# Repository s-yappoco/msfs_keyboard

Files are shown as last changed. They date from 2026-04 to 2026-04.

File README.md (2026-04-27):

# MSFS Macro Keyboard for PS5

PS5版 Microsoft Flight Simulator 2024 (MSFS2024) に最適化した、27キー、7ロータリーエンコーダー搭載の自作マクロキーボードです。

## 特徴
* **PS5完全対応**: PS5版 MSFS2024 での動作を確認済み。
* **Vial対応**: 専用ソフトのインストール不要。ブラウザ上で簡単にキーアサインを変更できます。
* **膨大なレイヤー数**: 最大16レイヤーに対応し、機体ごとの複雑な操作も割り当て可能。
* **高度なマクロ**: 複雑なキーシーケンスをワンタップで実行。
* **LEDインジケーター**:
    * **SIM Rate確認**: 4番目のLEDの色で、現在のSIM Rateを視覚的に判別可能（ユーザーキーコード制御）。
    * **レイヤー確認**: 5番目のLEDの色で、現在選択中のレイヤーを一目で把握。

## 外観
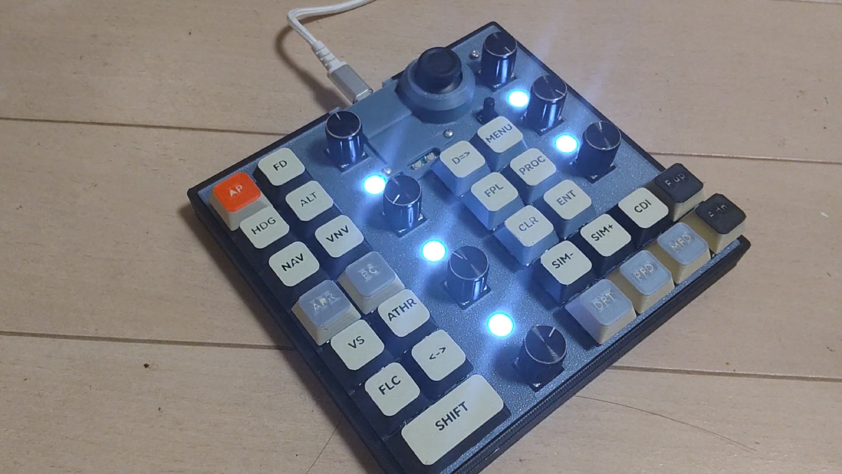
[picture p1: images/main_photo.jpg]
マクロキーボードの写真


## 基板の入手方法
本プロジェクトの専用プリント基板（PCB）は、メルカリにて頒布しています。
「**#MSFS2024自作キーボード**」で検索してください。
[メルカリで探す](https://jp.mercari.com/search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)

※基板とケースがセットになったものも、メルカリにて頒布を予定しています。

## 本キーボードの紹介 youtube
組み立ての様子、ファームウェアの書き込み、動作確認、MSFS2024 PS5版でのデモンストレーションをYouTubeで公開しています。
[youtubeで開く](https://youtu.be/_a79jdPi4Ig)

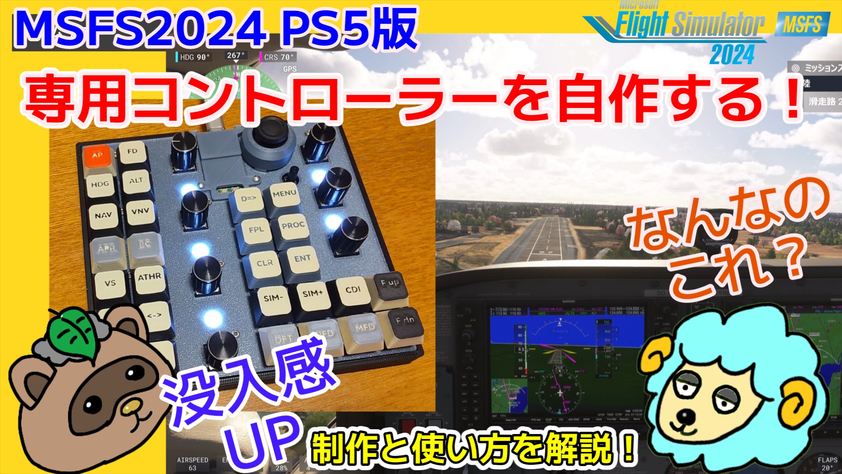
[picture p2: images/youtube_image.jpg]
youtube


## 回路図
[回路図(PDF)](msfs_keyboard_schematic.pdf)

## 必要部材 (BOM)

| リファレンス名 | 部品 | 数量 | 型式など | 主な入手先 |
| :--- | :--- | :---: | :--- | :--- |
| U1 | CPU基板 | 1 | RP2040マイコンボードキット | [秋月電子通商](https://akizukidenshi.com/catalog/g/g117542/) |
|　( SW1-19, SW21-28) | キースイッチ | 27 | cherry MX互換スイッチ | [遊舎工房でさがす](https://shop.yushakobo.jp/collections/cherry-mx-clone) |
| SW1-19, SW21-28 | キースイッチソケット | 27 | Kailh Switch Socket(MX用) | [遊舎工房](https://shop.yushakobo.jp/products/a01ps?variant=37665172521121) |
| RSW1-RSW7 | ロータリーエンコーダ | 7 | EC11 互換品 | [Amazon](https://www.amazon.co.jp/dp/B0C9QH83N6?ref=ppx_yo2ov_dt_b_fed_asin_title&th=1) |
| JSTICK1 | ジョイスティック | 1 | RKJXV122400R(アルプスアルパイン) | [秋月電子通商](https://akizukidenshi.com/catalog/g/g115951/) |
| SW20 | リセットスイッチ | 1 | TVD01-G73BB | [秋月電子通商](https://akizukidenshi.com/catalog/g/g109824/) |
| D1-D36 | ダイオード(SMD) | 36 | 1N4148W 互換 | [遊舎工房](https://shop.yushakobo.jp/products/a0800di-02-100) |
| LED1-LED5 | フルカラーLED | 5 | WS2812B 互換 | [遊舎工房](https://shop.yushakobo.jp/products/a0800ws-01-10) |
| C1-C5 | セラミックコンデンサ 0.1uF | 5 | 1608サイズ (省略可) | [秋月電子通商](https://akizukidenshi.com/catalog/g/g113374/) |
| - | インサートナット | 15 | M2 雌ねじ用(直径3mm×高さ3mm) | [Amazon](https://www.amazon.co.jp/dp/B0CTTLJL6S?ref=ppx_pop_dt_b_product_details&th=1) |
| - | パネル固定ねじ | 13 | M2ねじ 10mm | ホームセンター等 |
| - | CPUカバー取り付けねじ | 2 | M2ねじ 5mm | ホームセンター等 |
| - | アナログスティック交換用 | 1 | PS4コントローラ用 等 | [Amazon](https://www.amazon.co.jp/dp/B0C7C78LKB?ref=ppx_yo2ov_dt_b_fed_asin_title) |

## 筐体の入手方法
`3Dmodel_STL` フォルダにケース本体、トップパネル、ジョイスティックカバー、CPUカバーのSTLファイルを格納しています。<br>
3Dプリンターを用い、一般的なPLA素材での印刷が可能です。<br>
※基板とケースがセットになったものも、メルカリにて頒布を予定しています。
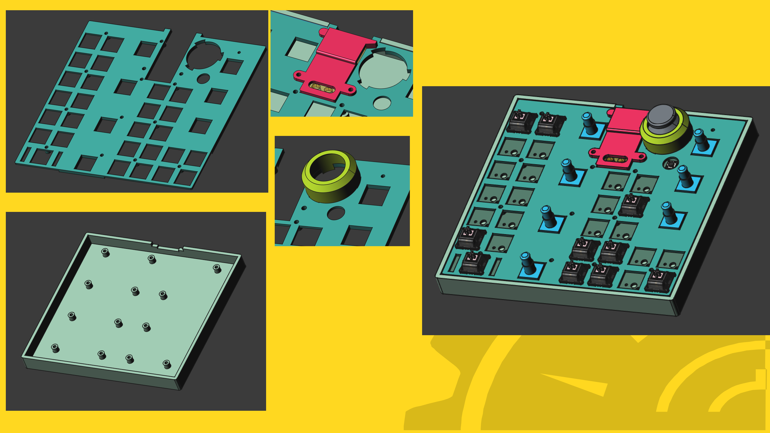
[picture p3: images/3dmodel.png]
3D model


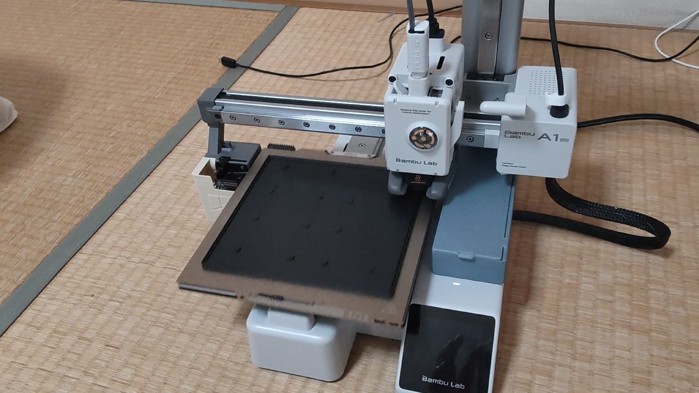
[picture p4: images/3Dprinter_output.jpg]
3Dプリンターでの印刷


## 組み立てに必要な道具
* **工具**: はんだごて、はんだ、ピンセット、ドライバー
* **あると便利なもの**: 虫めがね、テスター（導通確認用）
* **設定用**: PC、USBケーブル（ファームウェア書き込み・キーアサイン変更用）

## キーキャップの入手方法
市販のキーキャップのほか、3Dプリンターでの制作も可能です。

* **Keycap Generator**: [makerworldで開く](https://makerworld.com/en/models/1378891-keycap_generator#profileId-1426845)
  * このツールを利用して印刷したキーキャップのデータも `3Dmodel_STL` フォルダに同梱しています。(keycap_bambu.3mf)

## 設定方法
1. [Vial Web](https://get.vial.today/) にアクセスします。
2. キーボードを接続し、ブラウザ上でキーアサインやマクロを自由に編集してください。

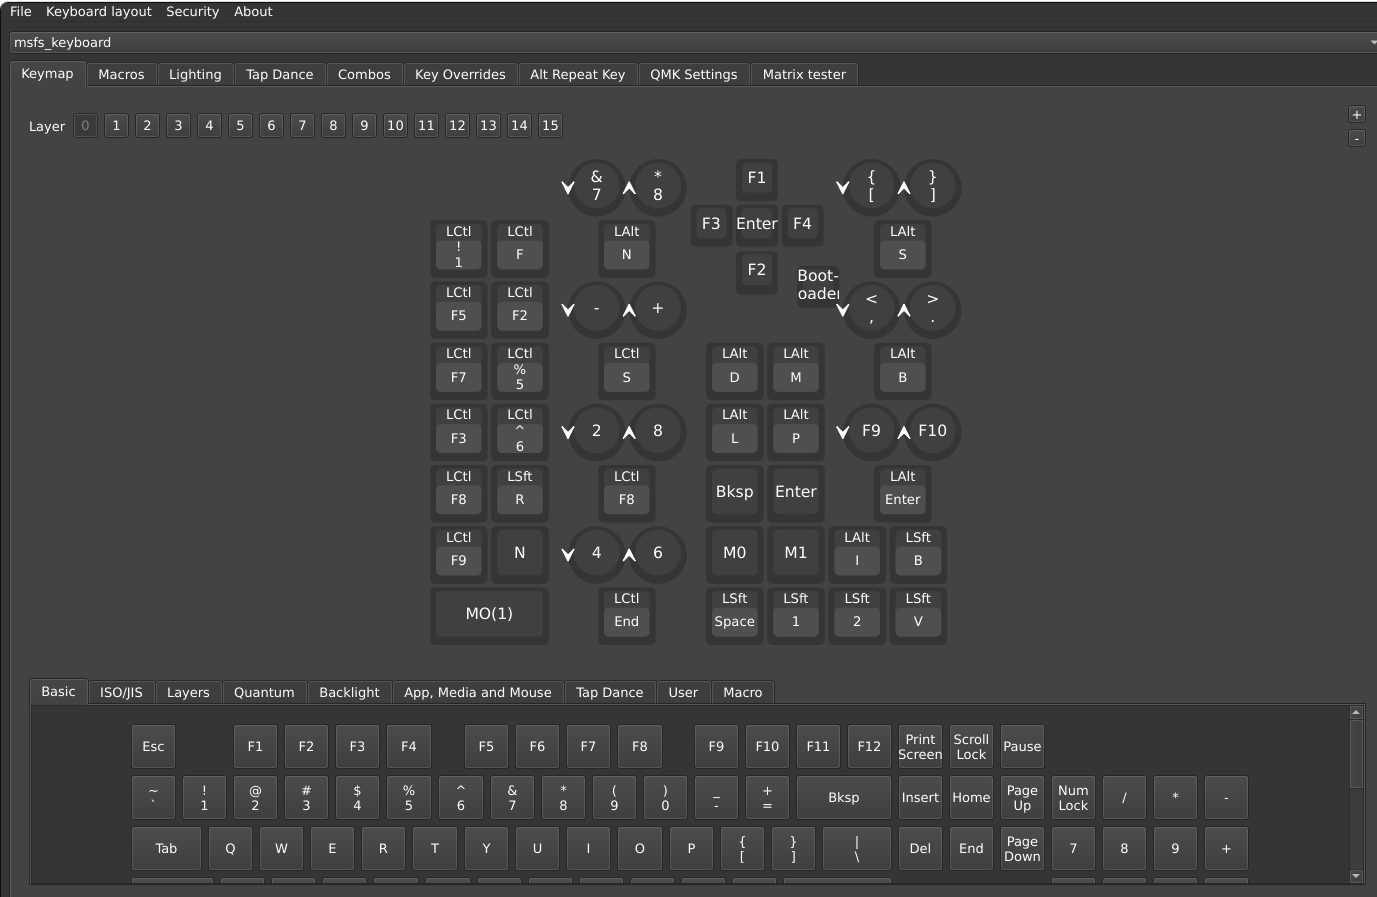
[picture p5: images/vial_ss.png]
Vial設定画面


## 開発環境
* Firmware: QMK / Vial
* MCU: RP2040

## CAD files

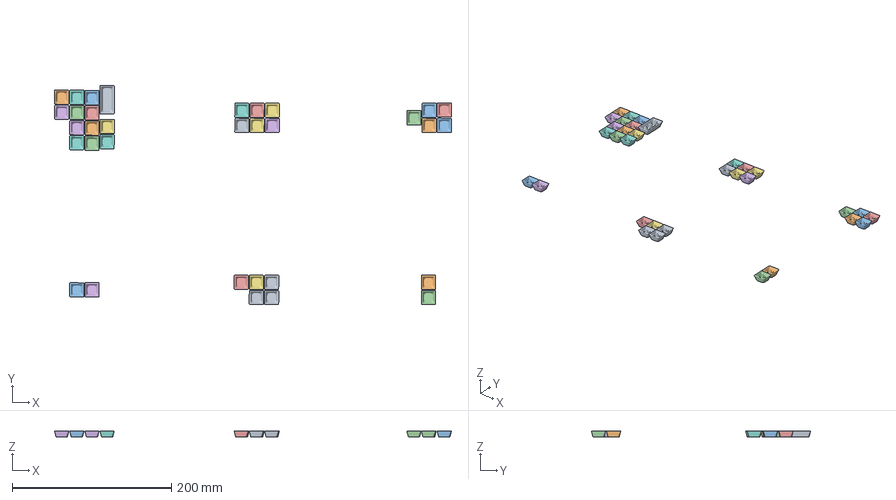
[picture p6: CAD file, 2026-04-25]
3Dmodel_STL/keycap_bambu.3mf
498.4 x 275.4 x 8.01 mm
shift_key.stl
Fup.stl
SIM_M.stl
Fdn.stl
SIM_P.stl
DISC.stl x 2
ATHR.stl
FLC.stl
Parametric_Model_Maker_1_3
Parametric_Model_Maker_1_2
Parametric_Model_Maker_1_17
Parametric_Model_Maker_1_22
Parametric_Model_Maker_1_6
Parametric_Model_Maker_1_4
Parametric_Model_Maker_1_24
Parametric_Model_Maker_1_15
Parametric_Model_Maker_1_23
Parametric_Model_Maker_1_1
Parametric_Model_Maker_1_18
Parametric_Model_Maker_1_21
Parametric_Model_Maker_1_16
Parametric_Model_Maker_1_10
Parametric_Model_Maker_1_14
Parametric_Model_Maker_1_5
Parametric_Model_Maker_1_19
Parametric_Model_Maker_1_20
Parametric_Model_Maker_1_13
Parametric_Model_Maker_1_9
Parametric_Model_Maker_1_7
Parametric_Model_Maker_1_8
Parametric_Model_Maker_1_11
Parametric_Model_Maker_1_12

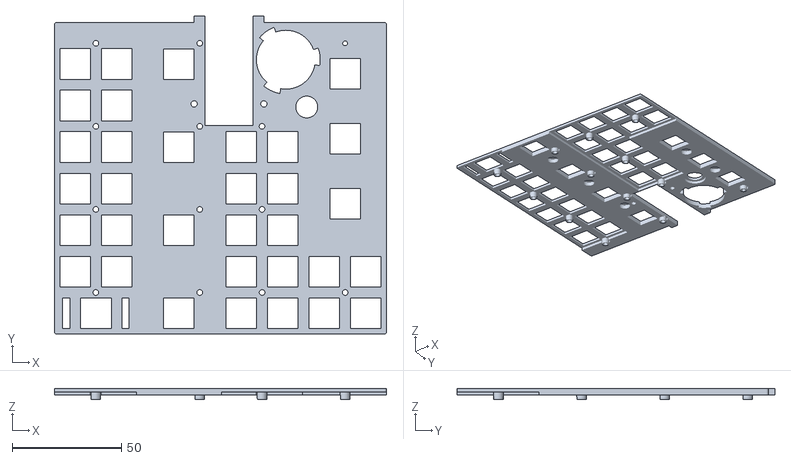
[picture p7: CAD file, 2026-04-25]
3Dmodel_STL/top_panel.stl
152.4 x 145.9 x 5.00

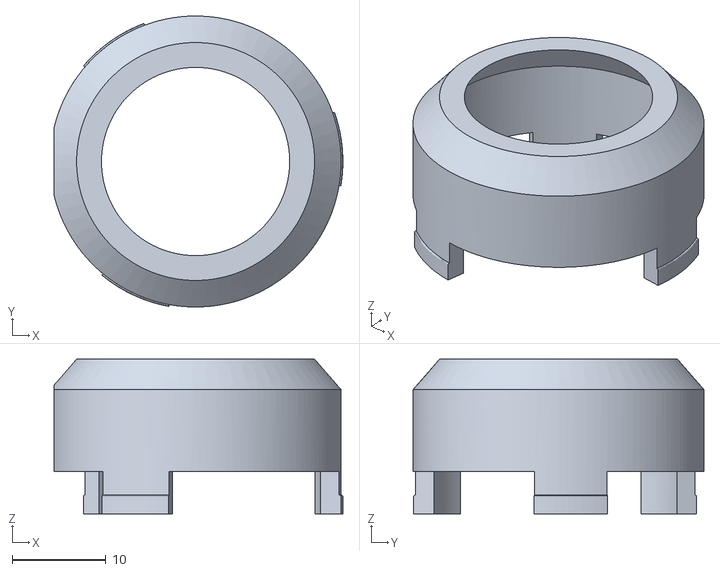
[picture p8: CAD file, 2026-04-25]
3Dmodel_STL/joystick_cover.stl
30.8 x 31.0 x 16.5

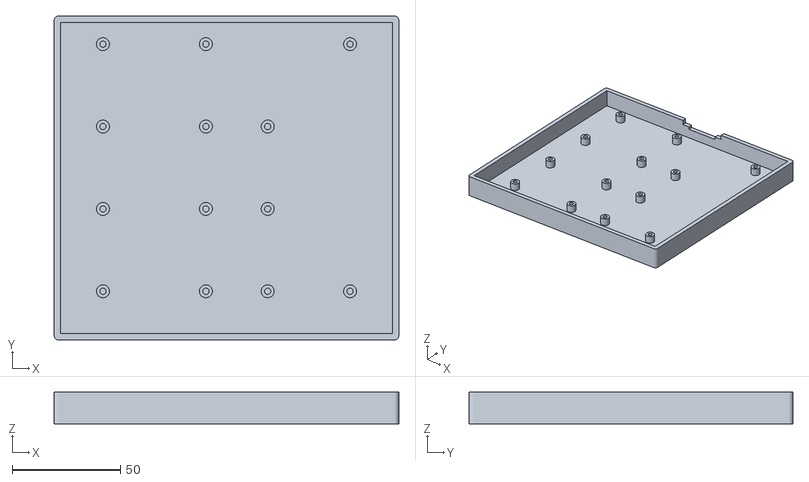
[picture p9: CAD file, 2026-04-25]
3Dmodel_STL/case.stl
159.4 x 149.9 x 14.6

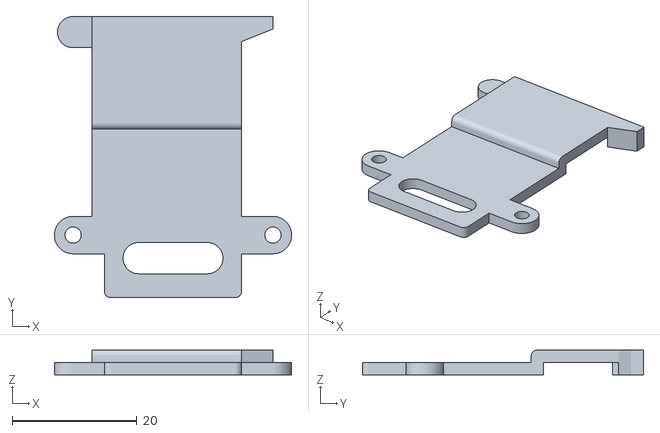
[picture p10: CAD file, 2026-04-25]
3Dmodel_STL/CPU_cover.stl
38.0 x 45.0 x 4.00

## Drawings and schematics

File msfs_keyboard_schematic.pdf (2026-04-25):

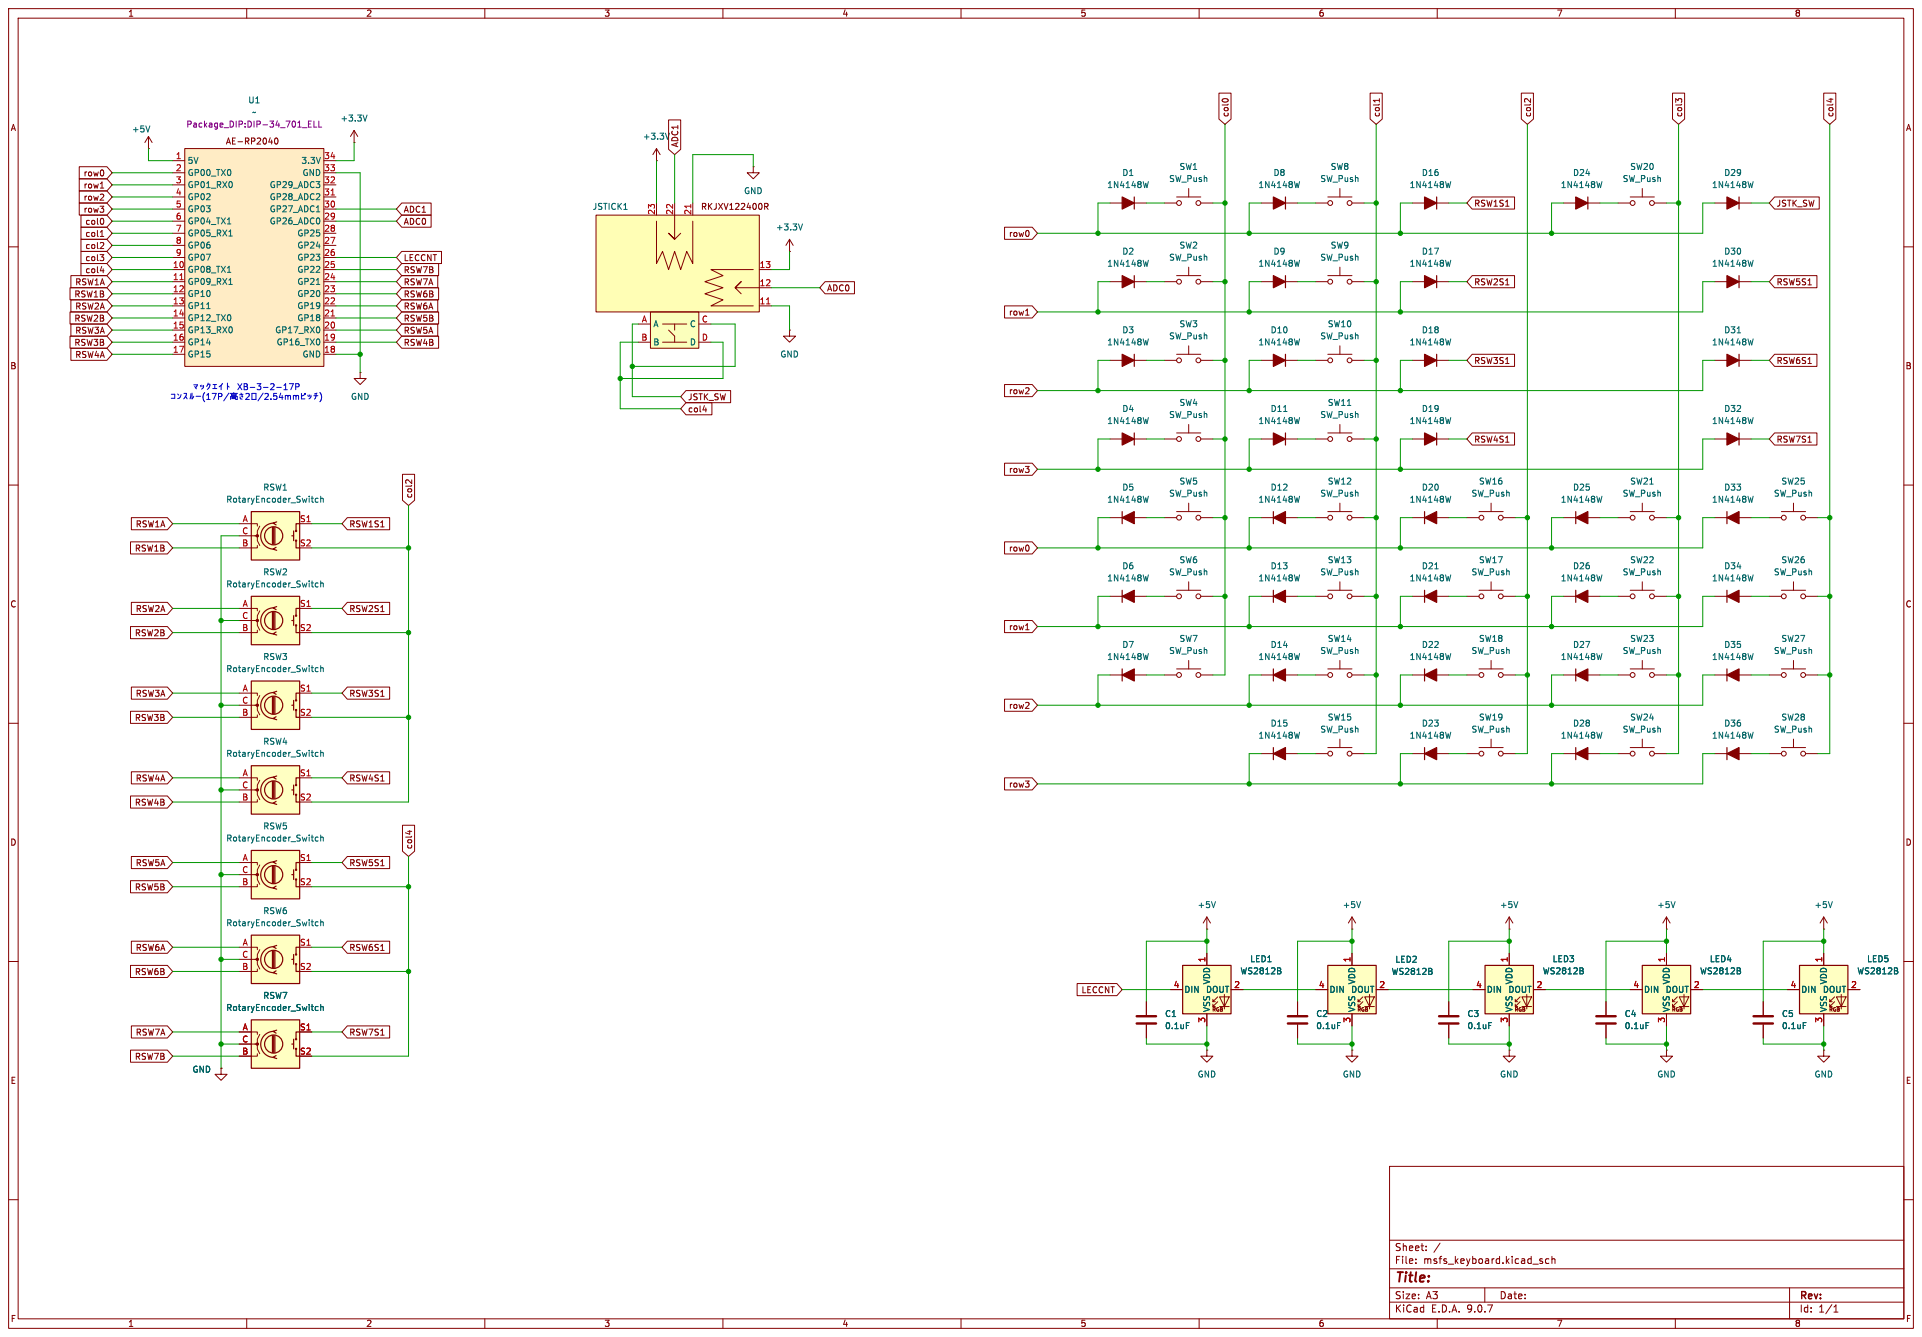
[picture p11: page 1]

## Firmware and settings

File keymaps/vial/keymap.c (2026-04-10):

// Copyright 2023 QMK
// SPDX-License-Identifier: GPL-2.0-or-later

#include QMK_KEYBOARD_H

////////////////// SIM rateの状況をLED3に出すための処理
// LEDのみの制御なので、実際のsim rate制御はゲーム内へキーコードを贈る必要がある。
// マクロで以下の色変更キーコードとゲームへ送信するキーコードを組み合わせておくと便利
// ミッションを始める前にKC_SIMRSTを発行して、基本速度に戻しておく

///////////////////////////////////////////////////////////////////// LED制御定義関連
// 点灯色定義
// 各レイヤー用の点灯色定義 (4番目のLEDのみを上書き) 
// RGBLIGHT_LAYER_SEGMENTS({LEDの開始位置, 個数, HSV色})
const rgblight_segment_t PROGMEM layer1_indicator[]  = RGBLIGHT_LAYER_SEGMENTS({4, 1, HSV_RED});
const rgblight_segment_t PROGMEM layer2_indicator[]  = RGBLIGHT_LAYER_SEGMENTS({4, 1, HSV_BLUE});
const rgblight_segment_t PROGMEM layer3_indicator[]  = RGBLIGHT_LAYER_SEGMENTS({4, 1, HSV_GREEN});
const rgblight_segment_t PROGMEM layer4_indicator[]  = RGBLIGHT_LAYER_SEGMENTS({4, 1, HSV_YELLOW});
const rgblight_segment_t PROGMEM layer5_indicator[]  = RGBLIGHT_LAYER_SEGMENTS({4, 1, HSV_MAGENTA});
const rgblight_segment_t PROGMEM layer6_indicator[]  = RGBLIGHT_LAYER_SEGMENTS({4, 1, HSV_CYAN});
const rgblight_segment_t PROGMEM layer7_indicator[]  = RGBLIGHT_LAYER_SEGMENTS({4, 1, HSV_ORANGE});
const rgblight_segment_t PROGMEM layer8_indicator[]  = RGBLIGHT_LAYER_SEGMENTS({4, 1, HSV_PURPLE});
const rgblight_segment_t PROGMEM layer9_indicator[]  = RGBLIGHT_LAYER_SEGMENTS({4, 1, HSV_SPRINGGREEN});
const rgblight_segment_t PROGMEM layer10_indicator[] = RGBLIGHT_LAYER_SEGMENTS({4, 1, HSV_TURQUOISE});
const rgblight_segment_t PROGMEM layer11_indicator[] = RGBLIGHT_LAYER_SEGMENTS({4, 1, HSV_TEAL});
const rgblight_segment_t PROGMEM layer12_indicator[] = RGBLIGHT_LAYER_SEGMENTS({4, 1, HSV_AZURE});
const rgblight_segment_t PROGMEM layer13_indicator[] = RGBLIGHT_LAYER_SEGMENTS({4, 1, HSV_PURPLE}); 
const rgblight_segment_t PROGMEM layer14_indicator[] = RGBLIGHT_LAYER_SEGMENTS({4, 1, HSV_CORAL}); 
const rgblight_segment_t PROGMEM layer15_indicator[] = RGBLIGHT_LAYER_SEGMENTS({4, 1, HSV_GOLD});

// SimRate インジケーター用 点灯色定義　全部で9色　(3番目のLEDのみを上書き) 
// RGBLIGHT_LAYER_SEGMENTS({LEDの開始位置, 個数, HSV色})
const rgblight_segment_t PROGMEM layer1_simrateled[] = RGBLIGHT_LAYER_SEGMENTS({3, 1, HSV_BLUE});        // -4: 極低速 (青)
const rgblight_segment_t PROGMEM layer2_simrateled[] = RGBLIGHT_LAYER_SEGMENTS({3, 1, HSV_CYAN});        // -3: 低速 (水色)
const rgblight_segment_t PROGMEM layer3_simrateled[] = RGBLIGHT_LAYER_SEGMENTS({3, 1, HSV_GREEN});       // -2: 中低速 (緑)
const rgblight_segment_t PROGMEM layer4_simrateled[] = RGBLIGHT_LAYER_SEGMENTS({3, 1, HSV_SPRINGGREEN}); // -1: 微低速 (黄緑)
const rgblight_segment_t PROGMEM layer5_simrateled[] = RGBLIGHT_LAYER_SEGMENTS({3, 1, HSV_WHITE});       //  0: 標準 (1x)
const rgblight_segment_t PROGMEM layer6_simrateled[] = RGBLIGHT_LAYER_SEGMENTS({3, 1, HSV_YELLOW});      //  1: 微高速 (黄)
const rgblight_segment_t PROGMEM layer7_simrateled[] = RGBLIGHT_LAYER_SEGMENTS({3, 1, HSV_ORANGE});      //  2: 中高速 (橙)
const rgblight_segment_t PROGMEM layer8_simrateled[] = RGBLIGHT_LAYER_SEGMENTS({3, 1, HSV_RED});         //  3: 高速 (赤)
const rgblight_segment_t PROGMEM layer9_simrateled[] = RGBLIGHT_LAYER_SEGMENTS({3, 1, HSV_MAGENTA});     //  4: 最高速 (ピンク/マゼンタ)


// sim_rateによる色変更用 カスタムキーコードの定義
enum my_keycodes {
    KC_SIMUP = QK_KB_0,			// SIMレートを1段階上げる（LEDの色設定のみ）
    KC_SIMDN,					// SIMレートを1段階下げる（LEDの色設定のみ）
    KC_SIMRST,					// SIMレートを基本速度に戻す（LEDの色設定のみ）
};

// --- 速度状態の管理変数 ---
static signed char sim_rate_level = 0;		// -15～15とする。0が通常速度


// RGB LIGHT制御 レイヤー定義
// RGB LIGHTはレイヤーでの制御となっていて、重ねて点灯制御できる。
const rgblight_segment_t* const PROGMEM my_rgb_layers[] = RGBLIGHT_LAYERS_LIST(
	// キーアサインレイヤー毎にLED4を点灯させるためのレイヤー登録（15色）
    layer1_indicator,  // Index 0
    layer2_indicator,  // Index 1
    layer3_indicator,  // Index 2
    layer4_indicator,  // Index 3
    layer5_indicator,  // Index 4
    layer6_indicator,  // Index 5
    layer7_indicator,  // Index 6
    layer8_indicator,  // Index 7
    layer9_indicator,  // Index 8
    layer10_indicator, // Index 9
    layer11_indicator, // Index 10
    layer12_indicator, // Index 11
    layer13_indicator, // Index 12
    layer14_indicator, // Index 13
    layer15_indicator, // Index 14
	
	// SIMレート速度毎にLED3を点灯させるためのレイヤー登録（9色）
	layer1_simrateled, // Index 15
	layer2_simrateled, // Index 16
	layer3_simrateled, // Index 17
	layer4_simrateled, // Index 18
	layer5_simrateled, // Index 19
	layer6_simrateled, // Index 20
	layer7_simrateled, // Index 21
	layer8_simrateled, // Index 22
	layer9_simrateled  // Index 23	
);


///////////////////////////////////////////////////////////////////// キーマップ定義
const uint16_t PROGMEM keymaps[][MATRIX_ROWS][MATRIX_COLS] = {
	
	[0] = LAYOUT(
        // 左側1列目 (SW1-SW6): ご指定の修正案
        LCTL(KC_1),     // SW1: AP (LC + 1) 
        LCTL(KC_F5),    // SW2: HDG (LC + F5)
        LCTL(KC_F7),    // SW3: NAV (LC + F7) 
        LCTL(KC_F3),    // SW4: APR (LC + F3)
        LCTL(KC_F8),    // SW5: VS (LC + F8) 
        LCTL(KC_F9),    // SW6: FLC (LC + F9)


        // 左側2列目 (SW8-SW13): ご指定の修正案 + 標準補完
        LCTL(KC_F),     // SW8: FD (L-Ctrl + F)
        LCTL(KC_F2),    // SW9: ALT (LC + F2)
        LCTL(KC_5),     // SW10: VNV (予備 LC + 5)
        LCTL(KC_6),     // SW11: BC (予備 LC + 6)
        LSFT(KC_R),     // SW12: ATHR (L-Shift + R)
        KC_N,           // SW13: NAV周波数スワップ (N)
		
        // シフトキー (SW7) レイヤー切り替え
        MO(1),

        // エンコーダ左側押し込み (RSW1S1-RSW4S1)
        LALT(KC_N),     // RSW1: NAV 1/2切り替え
        LCTL(KC_S),     // RSW2: ALT Sync
        LCTL(KC_F8),    // RSW3: VS (予備)
        LCTL(KC_END),   // RSW4: HDG Sync

        // 右側上半分 (FMS系: 衝突回避L-Alt+文字)
        LALT(KC_D),     // SW16: Direct-To
        LALT(KC_L),     // SW17: FPL
        KC_BSPC,        // SW21: CLR
        LALT(KC_M),     // SW25: MENU
        LALT(KC_P),     // SW26: PROC
        KC_ENT,         // SW22: ENT

        // 下段8つ (リクエスト配置 + 標準フラップアサイン)
        LALT(KC_UP),    // SW14: SIM + 
        LALT(KC_DOWN),  // SW18: SIM - 
        LALT(KC_I),     // SW23: CDI
        LSFT(KC_B),     // SW27: FLP - (フラップを上げる/格納)
        LSFT(KC_SPC),   // SW15: DFT (視点リセット)
        LSFT(KC_KP_1),  // SW19: PFD拡大
        LSFT(KC_KP_2),  // SW24: MFD拡大
        LSFT(KC_V),     // SW28: FLP + (フラップを下げる/展開)

        // エンコーダ右側押し込み
        LALT(KC_S),     // RSW5: Map Cursor
        LALT(KC_B),     // RSW6: BARO Set (B)
		LALT(KC_ENT),   // RSW7: FMS Cursor

        // ジョイスティック
        KC_ENT,         // ジョイスティック押し込み
        LCTL(KC_UP), 	// 上
		LCTL(KC_DOWN), 	// 下
		LCTL(KC_RIGHT), // 右
		LCTL(KC_LEFT),  // 左
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

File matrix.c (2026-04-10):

#include "matrix.h"
#include "quantum.h"

// ADCを動かすためのヘッダファイル
#include "analog.h"

// アナログスティックの読み取り設定
// 閾値を10bit(0-1023)用に調整
// 中央値512
// ヒステリシスを持たせている

#define STICK_THRESHOLD_HIGH 800
#define STICK_THRESHOLD_LOW  200
#define STICK_HYSTERESIS     50

// キーマトリックス接続ピン設定
static pin_t row_pins[] = {GP0, GP1, GP2, GP3};
static pin_t col_pins[] = {GP4, GP5, GP6, GP7, GP8};

// マトリックス初期化関数
void matrix_init_custom(void) {
    // 全てのピンを入力プルダウンに初期化
    for (uint8_t i = 0; i < 4; i++) {
        setPinInputLow(row_pins[i]);
    }
    for (uint8_t i = 0; i < 5; i++) {
        setPinInputLow(col_pins[i]);
    }	
}

// カスタムマトリックス読み取り関数を定義
// 日本式dualマトリックスを採用
// 基本はrow2col方式とし、row4,col5であるが、rowは逆方向にもあるので、0～7まで存在する。
//
// 実際にはスイッチのついていない以下のマトリックスは
// アナログスティックの読み取りに無理矢理割り当てるため、読み飛ばす処理を追加している
// UP [7, 0] DOWN [1, 3] LEFT [3, 3] RIGHT [2, 3]
	
bool matrix_scan_custom(matrix_row_t current_matrix[]) {
    bool changed = false;

    // --- 前半スキャン: Row(出力High) -> Col(入力) ---
    for (uint8_t i = 0; i < 5; i++) setPinInputLow(col_pins[i]); 

    for (uint8_t r = 0; r < 4; r++) {
        setPinOutput(row_pins[r]);
        writePinHigh(row_pins[r]);
        wait_us(30); 

        matrix_row_t row_data = 0;
        for (uint8_t c = 0; c < 5; c++) {
			// スキップ対象: [1,3], [2,3], [3,3]
            if (c == 3 && (r == 1 || r == 2 || r == 3)) {
                // 現在のマトリクス値を維持（ADC判定側で上書きするため）
                if (current_matrix[r] & (1 << c)) {
                    row_data |= (1 << c);
                }
                continue;
            }
            if (readPin(col_pins[c])) {
                row_data |= (1 << c);
            }
        }

        if (current_matrix[r] != row_data) {
            current_matrix[r] = row_data;
            changed = true;
        }

        writePinLow(row_pins[r]);
        setPinInputLow(row_pins[r]);
        wait_us(30);
    }

    // --- 後半スキャン: Col(出力High) -> Row(入力) ---
    for (uint8_t i = 0; i < 4; i++) setPinInputLow(row_pins[i]); 

    for (uint8_t c = 0; c < 5; c++) {
        setPinOutput(col_pins[c]);
        writePinHigh(col_pins[c]);
        wait_us(30);

        for (uint8_t r = 0; r < 4; r++) {
			// スキップ対象: [3,0] (後半スキャンなので current_matrix[r+4] 側)
            // c=0, r=3 の組み合わせをスキップ
            if (c == 0 && r == 3) {
                continue; 
            }
			
            matrix_row_t old_val = current_matrix[r + 4];
            
            if (readPin(row_pins[r])) {
                current_matrix[r + 4] |= (1 << c); // 押されたらビットを立てる
            } else {
                current_matrix[r + 4] &= ~(1 << c); // 離されたらビットを下ろす(重要!)
            }

            if (old_val != current_matrix[r + 4]) {
                changed = true;
            }
        }

        writePinLow(col_pins[c]);
        setPinInputLow(col_pins[c]);
        wait_us(30);
    }

	///////////////////////////////////////////////////////// アナログスティック読み取り
	// アナログスティックの入力を上下左右の4つのキーコードへ変換する
	// 基板上であいているキーマトリックスへ無理矢理配置する。
	// これで、キーアサインが通常のキースイッチと同様に自由に設定できる
    // UP [7, 0]
    // DOWN [1, 3]
    // LEFT [3, 3]
    // RIGHT [2, 3]
	
	// --- ADC読み取り  ---
    int16_t val_y = analogReadPin(GP26); // 上下
    int16_t val_x = analogReadPin(GP27); // 左右
	
    // X軸をLED2へ デバッグモード
//  rgblight_setrgb_at(val_x >> 2, 0,   0, 2);
	// Y軸をLED3へ デバッグモード
//	rgblight_setrgb_at(val_y >> 2, 0,   0, 3);

    // --- Y軸判定 (UP / DOWN) ---
    // UP [7, 0]
    if (val_y > (STICK_THRESHOLD_HIGH)) {
        if (!(current_matrix[7] & (1 << 0))) {
			current_matrix[7] |= (1 << 0);
			changed = true;
		}
    } else if (val_y < (STICK_THRESHOLD_HIGH - STICK_HYSTERESIS)) {
        if (current_matrix[7] & (1 << 0)) { 
			current_matrix[7] &= ~(1 << 0); 
			changed = true;
		}
    }

    // DOWN [1, 3]
    if (val_y < (STICK_THRESHOLD_LOW)) {
        if (!(current_matrix[1] & (1 << 3))) {
			current_matrix[1] |= (1 << 3); 
			changed = true;
		}
    } else if (val_y > (STICK_THRESHOLD_LOW + STICK_HYSTERESIS)) {
        if (current_matrix[1] & (1 << 3)) {
			current_matrix[1] &= ~(1 << 3);
			changed = true;
		}
	}

    // --- X軸判定 (RIGHT / LEFT) ---
    // LEFT [3, 3]
    if (val_x > (STICK_THRESHOLD_HIGH)) {
        if (!(current_matrix[3] & (1 << 3))) { 
			current_matrix[3] |= (1 << 3);
			changed = true;
		}
    } else if (val_x < (STICK_THRESHOLD_HIGH - STICK_HYSTERESIS)) {
        if (current_matrix[3] & (1 << 3)) {
			current_matrix[3] &= ~(1 << 3);
			changed = true;
		}
    }

    // RIGHT [2, 3]
    if (val_x < (STICK_THRESHOLD_LOW)) {
        if (!(current_matrix[2] & (1 << 3))) {
			current_matrix[2] |= (1 << 3);
			changed = true;
		}
    } else if (val_x > (STICK_THRESHOLD_LOW + STICK_HYSTERESIS)) {
        if (current_matrix[2] & (1 << 3)) {
			current_matrix[2] &= ~(1 << 3);
			changed = true;
		}
    }
    return changed;
}

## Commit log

2026-04-10 Add initial support for msfs_keyboard with custom matrix and Vial integration
    - Created README.md with project description and build instructions.
    - Added config.h to define TAP_CODE_DELAY for rotary encoder input.
    - Introduced keyboard.json to define keyboard specifications and features.
    - Implemented Vial keymap configuration in keymaps/vial directory.
    - Developed keymap.c for custom keycodes and RGB lighting control based on layers.
    - Configured rules.mk to enable Vial and encoder support.
    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
2026-04-10 readme変更
2026-04-11 Vial key assign ファイルを追加
2026-04-25 readmeに詳細な説明を追記＆3Dモデルデータを追加
    [CPU_cover.stl, case.stl, joystick_cover.stl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]
2026-04-25 回路図を追加
2026-04-27 youtubeリンク追加
2026-04-27 youtubeサムネイル追加
